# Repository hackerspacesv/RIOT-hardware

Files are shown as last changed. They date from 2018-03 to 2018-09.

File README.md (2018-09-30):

Hackerspace San Salvador RIOT OS Development Boards
===================================================
This repository contains all the design files for the boards supported by the
[RIOT OS](https://www.riot-os.org/) port mantained by the [Hackerspace
San Salvador](http://hackerspace.teubi.co/). You can find the RIOT OS port 
for the supported boards over
[https://github.com/hackerspacesv/RIOT](https://github.com/hackerspacesv/RIOT).

### Current boards supported
* **[ATSAMR21 Breakout Board](http://hackerspace.teubi.co/wiki/index.php?title=HSSV_ATSAMR21_Breakout_English)**: A development board to accelerate the deployment of
  IEEE 802.15.4 based networks on the 2.4Ghz band. It is based on the
  ATSAMR21G18-MR210UA module wich also includes support for antenna-diversity and
  a crypto-acceleration chip. This board was designed to be breadboard-friendly
  and includes USB support and power & LiPo battery management.
* **ATZB-RF-233-1-C breakout**: This is a breadboard-friendly breakout board for the
  module ATZB-RF-233-1-C, this module includes the easy-to-use AT8RF233 radio with
  a front-end-module with a Power-Amplifier & Low-Noise-Amplifier (PA/LNA) to greatly
  extend the range of the radio of IEEE 802.15.4 networks on the 2.4GHz band.

### Planned support
* **ATZB-RF-233-1-C breakout for the Omega Onion**: The Omega Onion is a low-cost
  system-on-a-module that runs a lightweight version of GNU/Linux. This breakout board
  should facilitate the creation of low-cost WiFi-802.15.4 bridges and edge routers.

### Board documentation

A guide to use this board with RIOT OS is available at the [Hackerspace San Salvador Wiki](http://hackerspace.teubi.co/wiki/index.php?title=HSSV_ATSAMR21_Breakout_English)

### Licensing and use
**Copyright 2018 Mario Gomez <mario.gomez@teubi.co>**

All files within this repository are licensed under the
Apache License, Version 2.0 (the "License") unless otherwise
specified in the individual files; you may not use this files
except in compliance with the License.

You may obtain a copy of the License at

    http://www.apache.org/licenses/LICENSE-2.0

Unless required by applicable law or agreed to in writing, software
and design files distributed under the License are distributed on an
"AS IS" BASIS, WITHOUT WARRANTIES OR CONDITIONS OF ANY KIND, either
express or implied.

See the License for the specific language governing permissions and
limitations under the License.

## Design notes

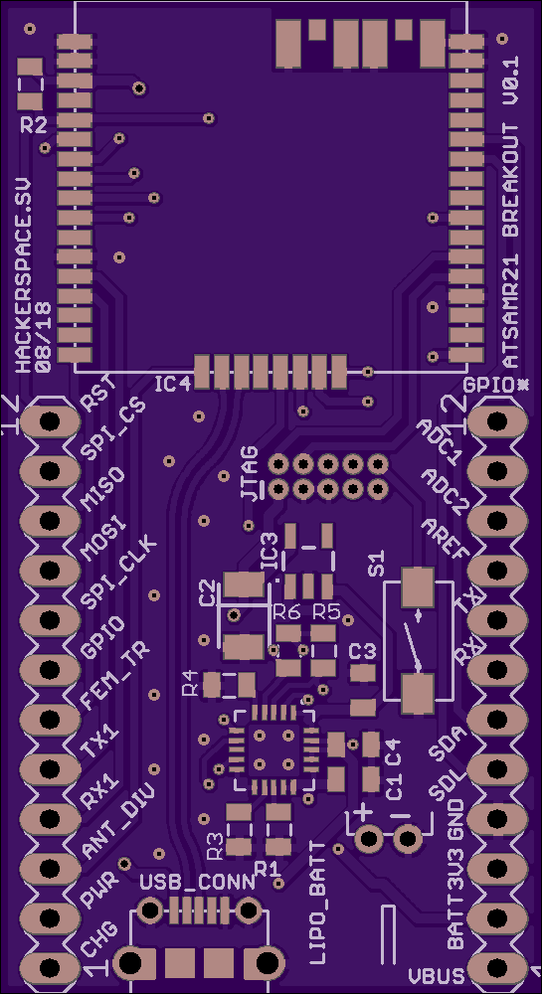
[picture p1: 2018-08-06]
boards/renders/ATSAMR21-Top.png

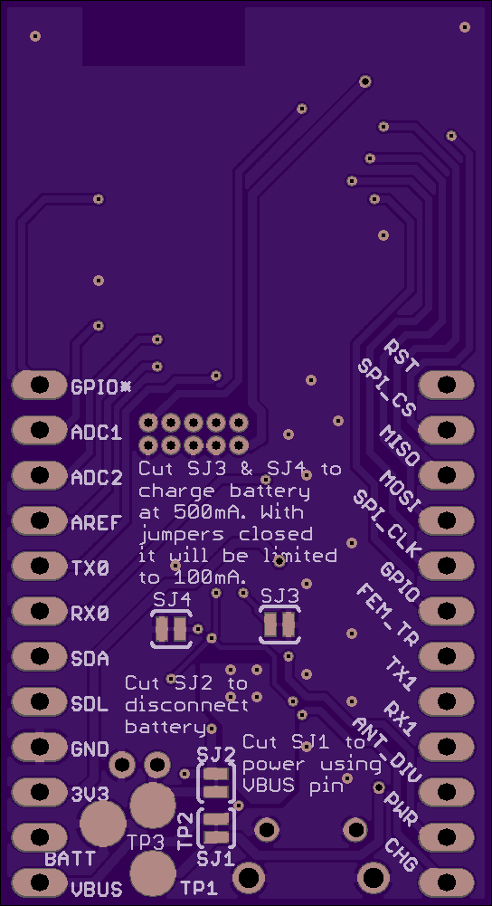
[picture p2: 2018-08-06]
boards/renders/ATSAMR21-Bottom.png

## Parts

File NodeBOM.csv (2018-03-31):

Qty | Value | Device | Package | Parts | Description | MF | MPN | OC_FARNELL | OC_NEWARK | PACKAGE | PROD_ID | SUPPLIER | TP_SIGNAL_NAME
1 |  | JST_2PIN-THM-RA | JST-PH-2-THM-RA | LIPO_BATT | JST 2-Pin Connectors of various flavors
2 |  | MA12-1 | MA12-1 | SV1, SV2 | PIN HEADER |  |  | unknown | unknown
1 | SI2301CDS-T1-GE3 | MOSFET-PCHANNEL | SOT23-3 | Q1 | Generic PMOSFET |  |  |  |  |  | TRANS-08285
2 | 10K | RESISTOR0805-RES | 0805 | R1, R2 | Resistor
1 | 1N5819HW-7-F | 1N5819HW-7-F | SOD123 | D1
1 | ATSAMR21G18-MR210UA | ATSAMR21G18-MR210UA | ATSAMR21G18A-MR210UA | IC4
1 | CORTEX_DEBUGPTH | CORTEX_DEBUGPTH | 2X5-PTH-1.27MM | JTAG | Cortex Debug Connector
1 | EVQ-PNF04M | EVQ-PNF04M | PANASONIC_EVQPE1/PN/5P | S1
1 | LTC4412 | LTC4412 | SOT23-6L | IC2
1 | MCP73831T-2ATI/OT | MCP73831T-2ATI/OT | SOT95P300X145-5N | IC1 | IC, BATT CHARGER, Li-Ion Li-Polymer, 500 mA |  | MCP73831T-2ATI/OT | 1834890 | 84R5196 | SOT23-5 |  | Microchip
1 | NCP4589DSN33T1G | NCP4589DSN33T1G | SOT23-5 | IC3
2 | SOLDERJUMPERTRACE | SOLDERJUMPERTRACE | SJ_2S-TRACE | SJ1, SJ2 | Solder Jumper
2 | TPB2,54 | TPB2,54 | B2,54 | TP1, TP2 | Test pad
2 | TPSB107M010R0400 | TPSB107M010R0400 | 1210-POLARIZED | C1, C2
1 | USB-MICRO-B | USB-MICRO-B | HPL511 | USB_CONN

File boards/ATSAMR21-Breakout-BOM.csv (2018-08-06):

Qty | Value | Device | Package | Parts | Description | MF | MPN | OC_FARNELL | OC_NEWARK | PROD_ID | TP_SIGNAL_NAME | VALUE
1 |  | JST_2PIN-THM-RA | JST-PH-2-THM-RA | LIPO_BATT | JST 2-Pin Connectors of various flavors
2 |  | MA12-1 | MA12-1 | SV1, SV2 | PIN HEADER |  |  | unknown | unknown
1 | 100K | RESISTOR0805-RES | 0805 | R3 | Resistor
4 | 10K | RESISTOR0805-RES | 0805 | R2, R4, R5, R6 | Resistor
1 | 10uF | 22UF-0805-6.3V-20% | 0805 | C4 | 22µF ceramic capacitors |  |  |  |  | CAP-08402 |  | 22uF
1 | 2K | RESISTOR0805-RES | 0805 | R1 | Resistor
2 | 4.7uF | 22UF-0805-6.3V-20% | 0805 | C1, C3 | 22µF ceramic capacitors |  |  |  |  | CAP-08402 |  | 22uF
1 | 47uF | TPSB107M010R0400 | 1210-POLARIZED | C2
1 | ATSAMR21G18-MR210UA | ATSAMR21G18-MR210UA | ATSAMR21G18A-MR210UA | IC4
1 | CORTEX_DEBUGPTH | CORTEX_DEBUGPTH | 2X5-PTH-1.27MM | JTAG | Cortex Debug Connector
1 | EVQ-PNF04M | EVQ-PNF04M | PANASONIC_EVQPE1/PN/5P | S1
1 | MCP73871T | MCP73871T | QFN-20 | U$1
1 | NCP4589DSN33T1G | NCP4589DSN33T1G | SOT23-5 | IC3
4 | SOLDERJUMPERTRACE | SOLDERJUMPERTRACE | SJ_2S-TRACE | SJ1, SJ2, SJ3, SJ4 | Solder Jumper
3 | TPB2,54 | TPB2,54 | B2,54 | TP1, TP2, TP3 | Test pad
1 | USB-MICRO-B | USB-MICRO-B | HPL511 | USB_CONN

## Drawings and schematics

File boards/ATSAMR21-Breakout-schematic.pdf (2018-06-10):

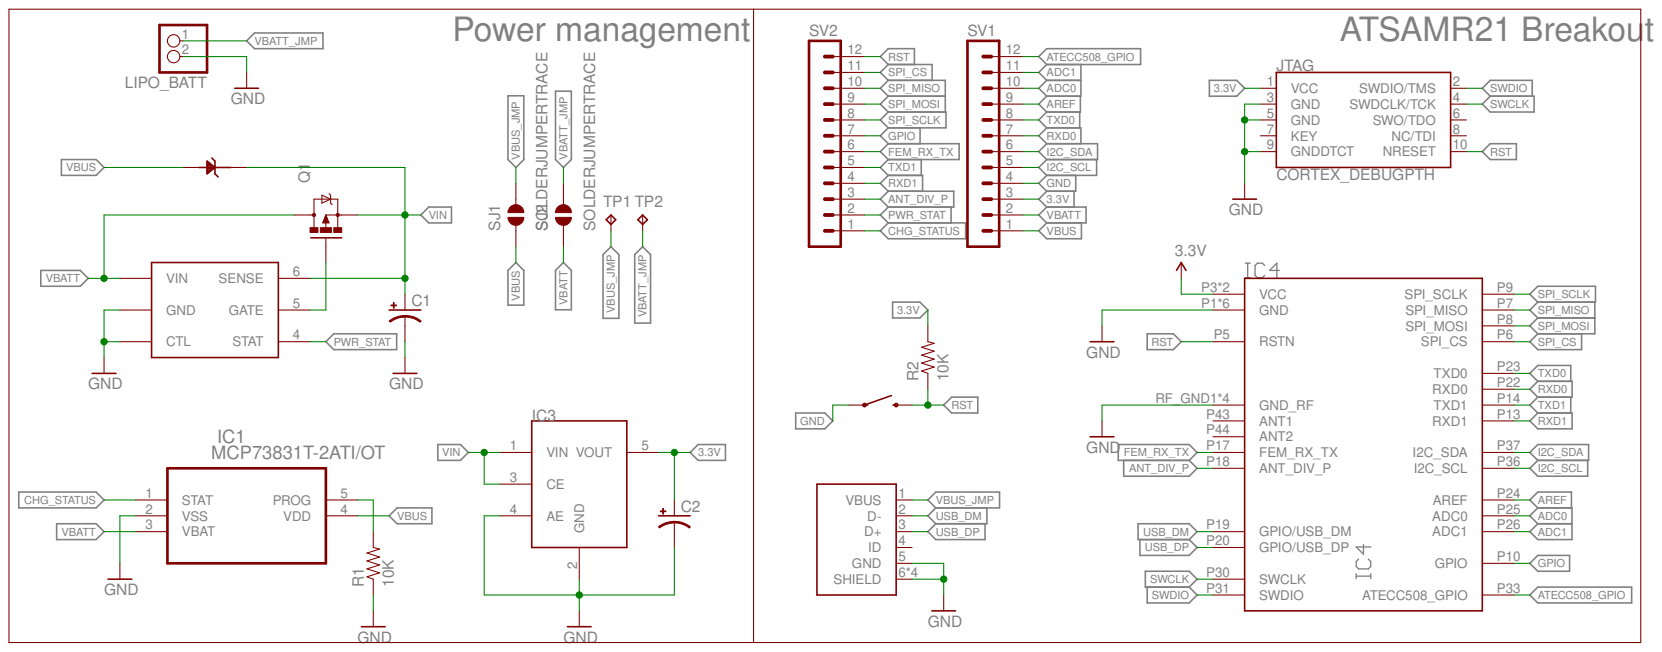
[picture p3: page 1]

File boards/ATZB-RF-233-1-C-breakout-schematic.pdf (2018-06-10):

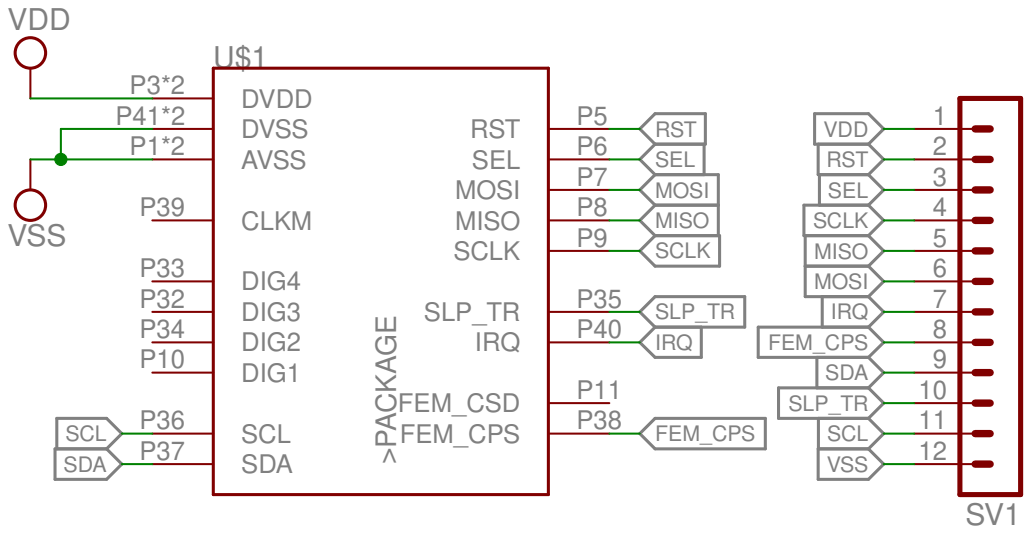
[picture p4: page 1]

>PACKAGE VSS VDD AVSS P1*2 DVDD P3*2 RST P5 SEL P6 MOSI P7 MISO P8 SCLK P9 DIG1 P10 FEM_CSD P11 DIG3 P32 DIG4 P33 DIG2 P34 SLP_TR P35 SCL P36 SDA P37 FEM_CPS P38 CLKM P39 DVSS P41*2 U$1 IRQ P40 SV1 123456789101112 VSS RST VDD SEL RST MOSI SEL MOSI MISO SCLK MISO SCLK SLP_TR SLP_TR IRQ IRQ FEM_CPS FEM_CPS SDA SDA SCL SCL

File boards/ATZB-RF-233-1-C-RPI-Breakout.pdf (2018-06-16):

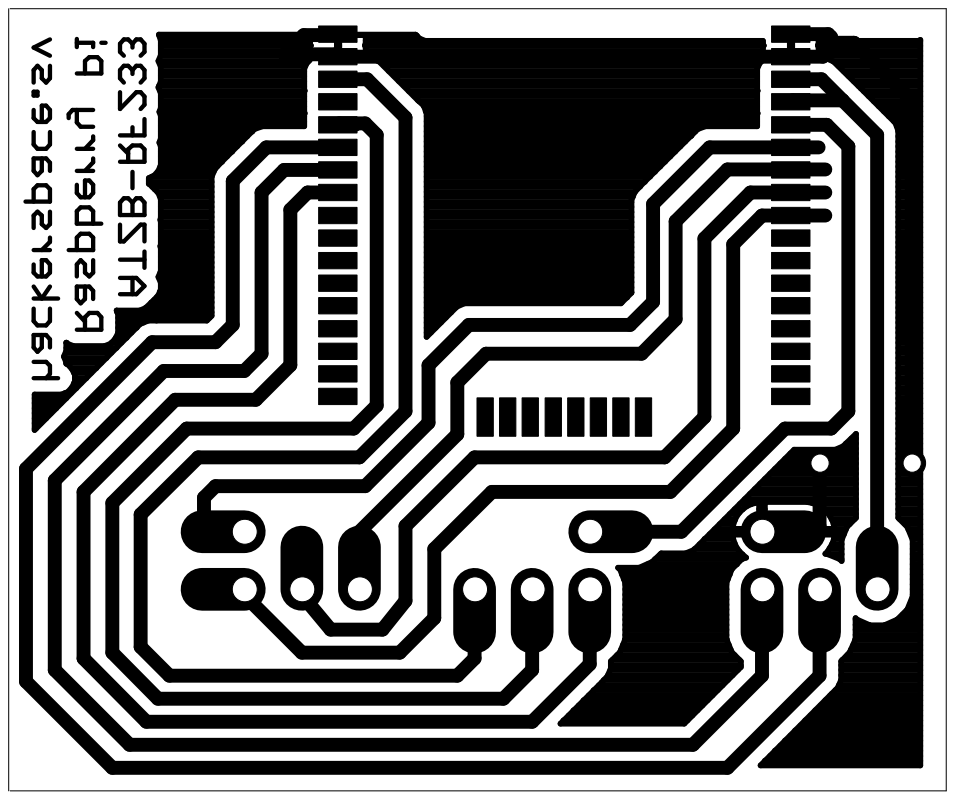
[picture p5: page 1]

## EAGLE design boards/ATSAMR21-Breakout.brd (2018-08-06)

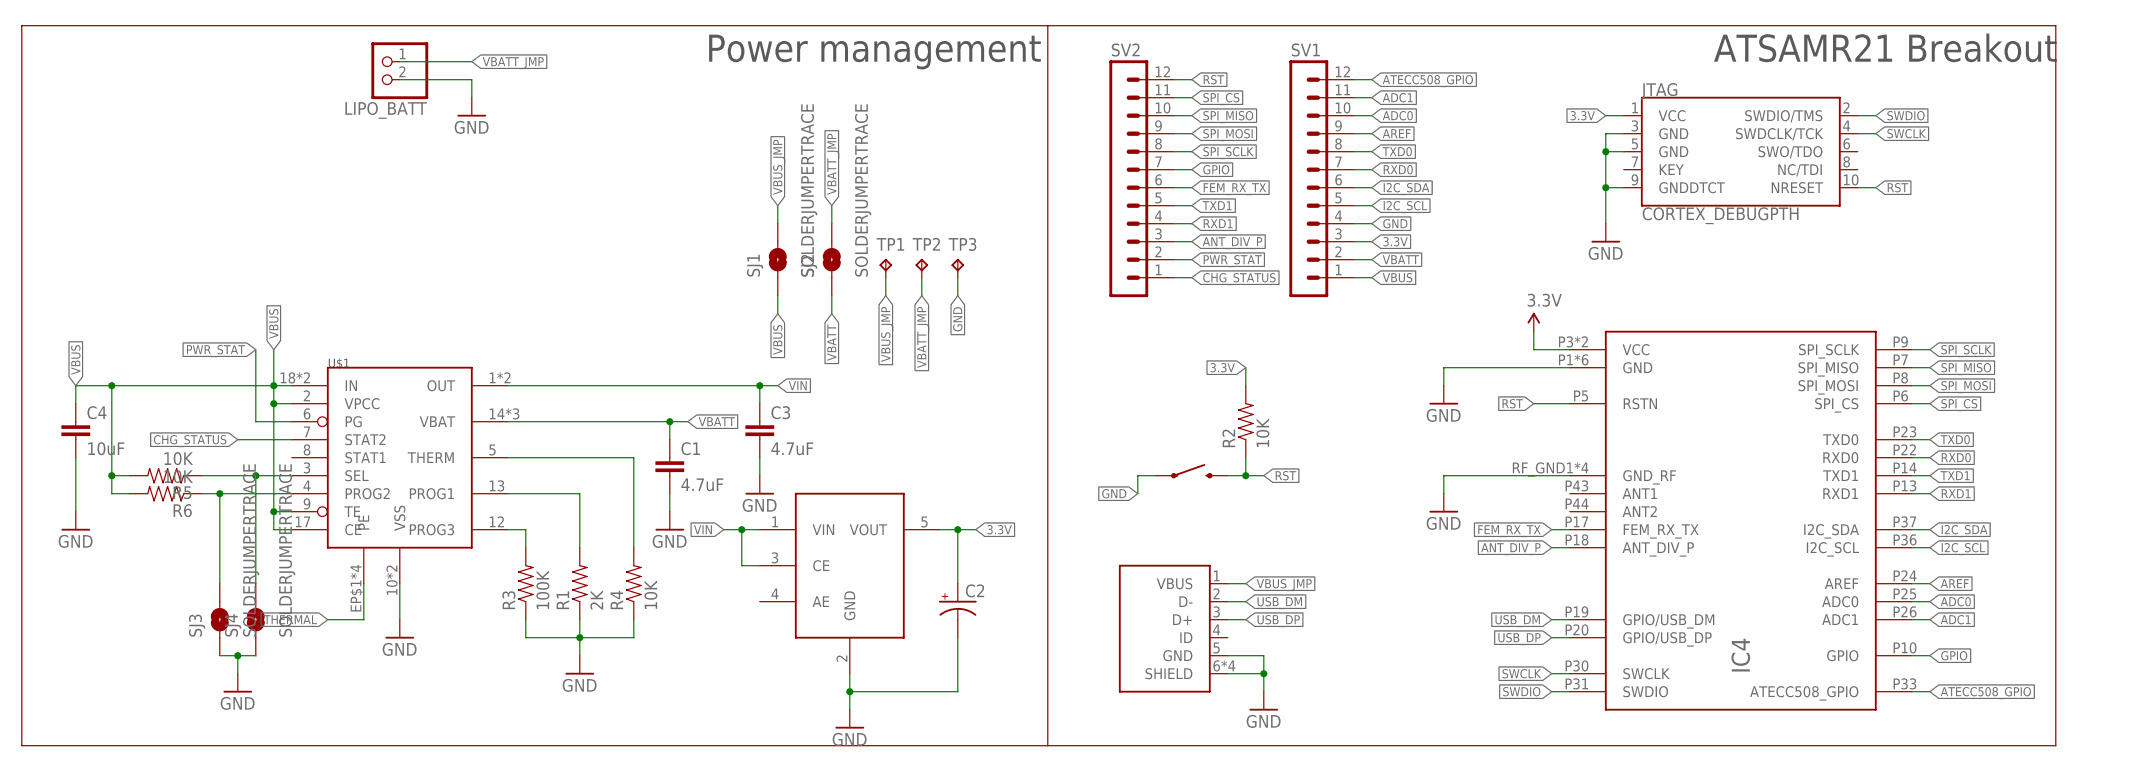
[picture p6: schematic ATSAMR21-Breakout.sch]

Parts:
C1, C3: 4.7uF; 0805
C2: 47uF; 1210-POLARIZED
C4: 10uF; 0805
IC3: NCP4589DSN33T1G; SOT23-5
IC4: ATSAMR21G18-MR210UA; ATSAMR21G18A-MR210UA
JTAG: CORTEX_DEBUGPTH; 2X5-PTH-1.27MM
LIPO_BATT: JST_2PIN-THM-RA; JST-PH-2-THM-RA
R1: 2K; 0805
R2, R4, R5, R6: 10K; 0805
R3: 100K; 0805
S1: EVQ-PNF04M; PANASONIC_EVQPE1/PN/5P
SJ1, SJ2, SJ3, SJ4: SOLDERJUMPERTRACE; SJ_2S-TRACE
SV1, SV2: MA12-1
TP1, TP2, TP3: TPB2,54; B2,54
U$1: MCP73871T; QFN-20
USB_CONN: USB-MICRO-B; HPL511

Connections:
3.3V: C2.1 (+), IC3.5 (VOUT), IC4.P3 (VCC), IC4.P4 (VCC), JTAG.1 (VCC), R2.2, SV1.3
ADC0: IC4.P25 (ADC0), SV1.10
ADC1: IC4.P26 (ADC1), SV1.11
ANT_DIV_P: IC4.P18 (ANT_DIV_P), SV2.3
AREF: IC4.P24 (AREF), SV1.9
ATECC508_GPIO: IC4.P33 (ATECC508_GPIO), SV1.12
CHG_STATUS: SV2.1, U$1.7 (STAT2)
FEM_RX_TX: IC4.P17 (FEM_RX_TX), SV2.6
GND: C1.2, C2.2 (-), C3.2, C4.2, IC3.2 (GND), IC4.P1 (GND), IC4.P2 (GND), IC4.P12 (GND), IC4.P29 (GND), IC4.P41 (GND), IC4.P42 (GND), IC4.RF_GND1 (GND_RF), IC4.RF_GND2 (GND_RF), IC4.RF_GND3 (GND_RF), IC4.RF_GND4 (GND_RF), JTAG.3 (GND), JTAG.5 (GND), JTAG.9 (GNDDTCT), LIPO_BATT.2 (1), R1.1, R3.1, R4.1, S1.P1 (1), SJ3.1, SJ4.1, SV1.4, TP3.TP, U$1.10 (VSS), U$1.11 (VSS), USB_CONN.5 (GND), USB_CONN.6 (SHIELD), USB_CONN.7 (SHIELD), USB_CONN.8 (SHIELD), USB_CONN.9 (SHIELD)
GPIO: IC4.P10 (GPIO), SV2.7
I2C_SCL: IC4.P36 (I2C_SCL), SV1.5
I2C_SDA: IC4.P37 (I2C_SDA), SV1.6
unnamed: R6.1, SJ3.2, U$1.4 (PROG2)
unnamed: R5.1, SJ4.2, U$1.3 (SEL)
unnamed: R3.2, U$1.12 (PROG3)
unnamed: R1.2, U$1.13 (PROG1)
unnamed: R4.2, U$1.5 (THERM)
PWR_STAT: SV2.2, U$1.6 (PG)
RST: IC4.P5 (RSTN), JTAG.10 (NRESET), R2.1, S1.P2 (2), SV2.12
RXD0: IC4.P22 (RXD0), SV1.7
RXD1: IC4.P13 (RXD1), SV2.4
SPI_CS: IC4.P6 (SPI_CS), SV2.11
SPI_MISO: IC4.P7 (SPI_MISO), SV2.10
SPI_MOSI: IC4.P8 (SPI_MOSI), SV2.9
SPI_SCLK: IC4.P9 (SPI_SCLK), SV2.8
SWCLK: IC4.P30 (SWCLK), JTAG.4 (SWDCLK/TCK)
SWDIO: IC4.P31 (SWDIO), JTAG.2 (SWDIO/TMS)
THERMAL: U$1.EP$1 (PE), U$1.EP$2 (PE), U$1.EP$3 (PE), U$1.EP$4 (PE)
TXD0: IC4.P23 (TXD0), SV1.8
TXD1: IC4.P14 (TXD1), SV2.5
USB_DM: IC4.P19 (GPIO/USB_DM), USB_CONN.2 (D-)
USB_DP: IC4.P20 (GPIO/USB_DP), USB_CONN.3 (D+)
VBATT: C1.1, SJ2.1, SV1.2, U$1.14 (VBAT), U$1.15 (VBAT), U$1.16 (VBAT)
VBATT_JMP: LIPO_BATT.1 (2), SJ2.2, TP2.TP
VBUS: C4.1, R5.2, R6.2, SJ1.1, SV1.1, U$1.2 (VPCC), U$1.9 (TE), U$1.17 (CE), U$1.18 (IN), U$1.19 (IN)
VBUS_JMP: SJ1.2, TP1.TP, USB_CONN.1 (VBUS)
VIN: C3.1, IC3.1 (VIN), IC3.3 (CE), U$1.1 (OUT), U$1.20 (OUT)

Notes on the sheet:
Power management
ATSAMR21 Breakout

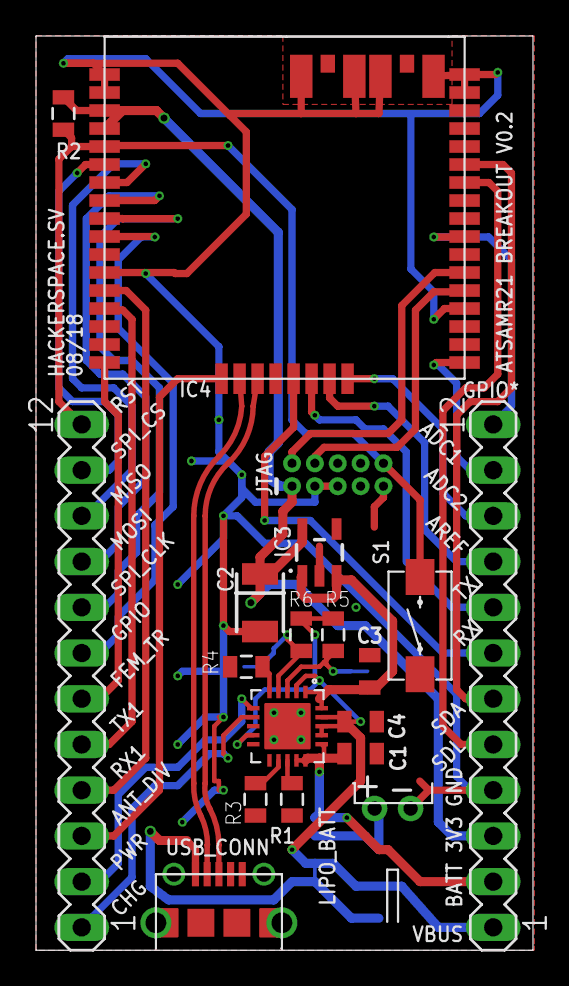
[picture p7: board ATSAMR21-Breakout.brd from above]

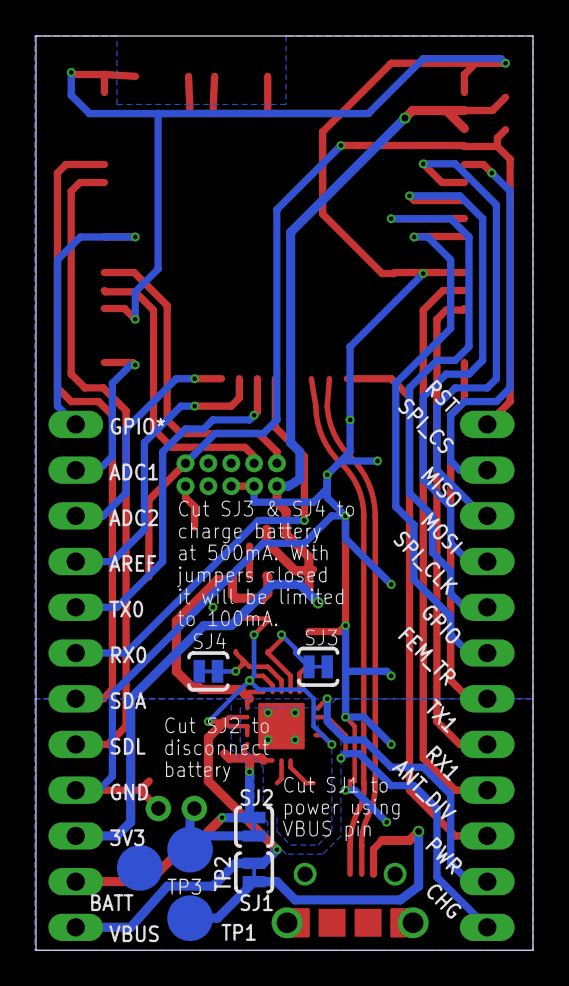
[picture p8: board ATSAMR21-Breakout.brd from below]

Board: 2 copper layers, 27.6 x 50.8 mm, 26 parts (7 on the bottom side), 37 nets.

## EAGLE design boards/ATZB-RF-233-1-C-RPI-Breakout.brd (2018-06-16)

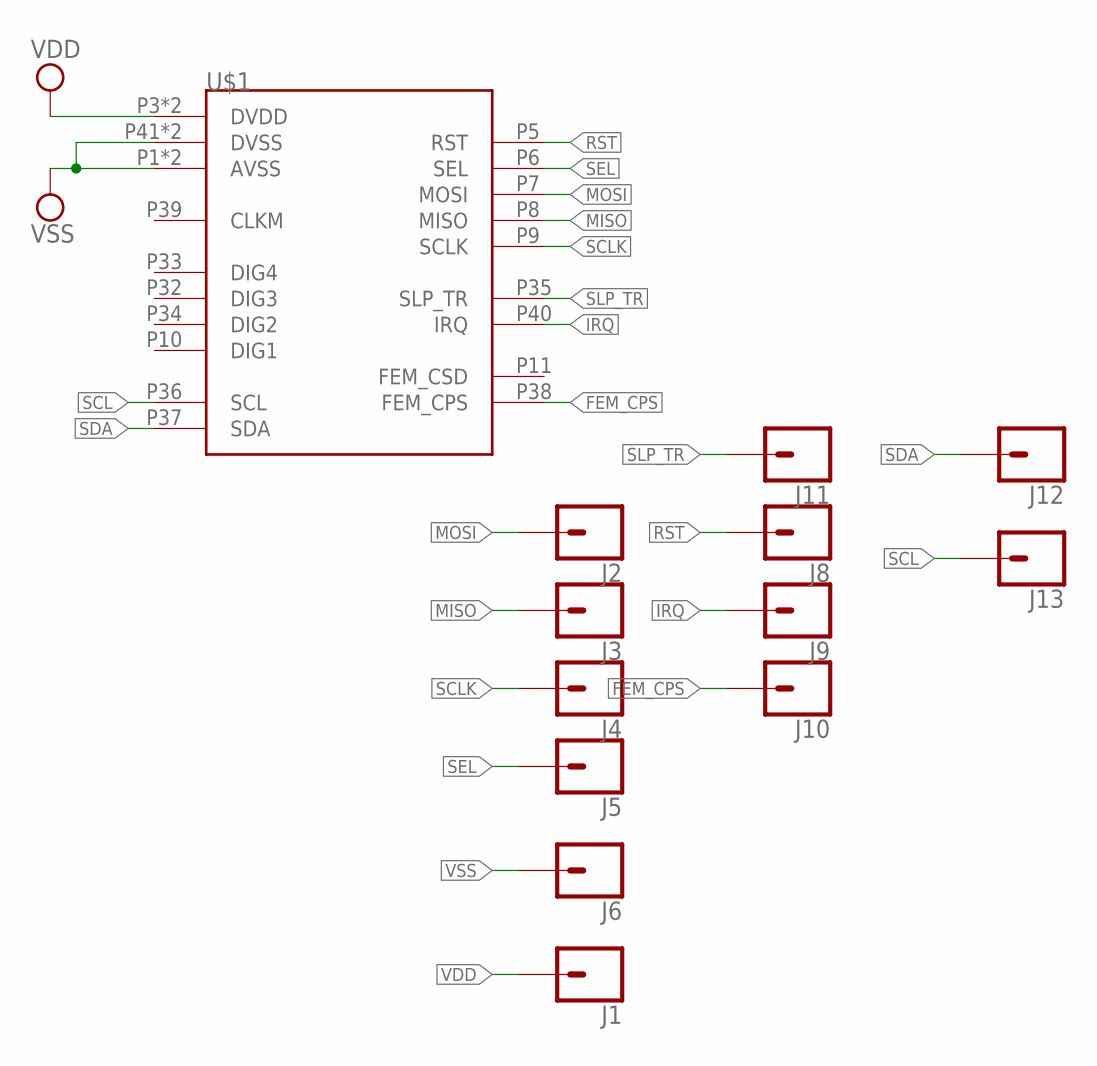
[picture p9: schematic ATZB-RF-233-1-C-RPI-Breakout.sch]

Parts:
J1, J2, J3, J4, J5, J6, J8, J9, J10, J11, J12, J13: CONN_01OFFSET; 1X01_OFFSET
U$1: ATZB-RF-233-1-C

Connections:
FEM_CPS: J10.1, U$1.P38 (FEM_CPS)
IRQ: J9.1, U$1.P40 (IRQ)
MISO: J3.1, U$1.P8 (MISO)
MOSI: J2.1, U$1.P7 (MOSI)
RST: J8.1, U$1.P5 (RST)
SCL: J13.1, U$1.P36 (SCL)
SCLK: J4.1, U$1.P9 (SCLK)
SDA: J12.1, U$1.P37 (SDA)
SEL: J5.1, U$1.P6 (SEL)
SLP_TR: J11.1, U$1.P35 (SLP_TR)
VDD: J1.1, U$1.P3 (DVDD), U$1.P4 (DVDD)
VSS: J6.1, U$1.P1 (AVSS), U$1.P2 (AVSS), U$1.P41 (DVSS), U$1.P42 (DVSS)

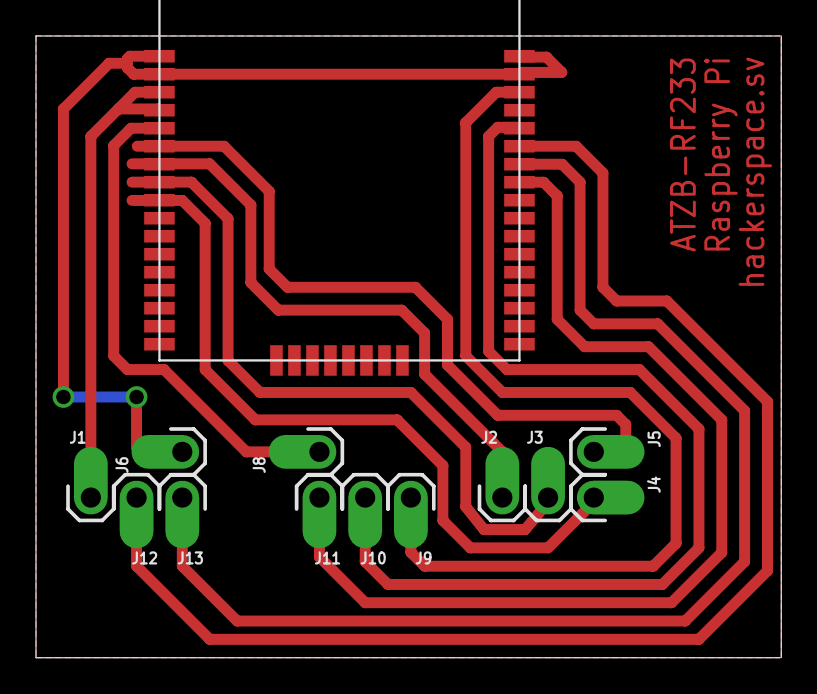
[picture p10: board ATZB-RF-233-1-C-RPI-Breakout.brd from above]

Board: 2 copper layers, 41.4 x 34.5 mm, 13 parts (0 on the bottom side), 12 nets.

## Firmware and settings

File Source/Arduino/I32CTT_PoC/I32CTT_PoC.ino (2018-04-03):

/*
 * 
 * This file is part of I32CTT (Integer 32-bit Control & Telemetry Transport).
 * Copyright (C) 2017 Mario Gomez.
 * 
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
 * You should have received a copy of the GNU General Public License
 * along with I32CTT.  If not, see <http://www.gnu.org/licenses/>.
 */

/*
 * Acerca de este archivo: Este sketch es la implementación de referencia
 * para el protocolo de enteros de 32 bits para control y transporte de
 * telemetría (I32CTT).
 */
// Utilizamos string.h para facilitar el formato de salida de Serie.
#include "I32CTT.h"
#include "I32CTT_NullEndpoint.h"
#include "I32CTT_ArduinoStreamInterface.h"
#include "I32CTT_Arduino802154Interface.h"
#include "MBL_ManualEndpoint.h"
#include <string.h>

I32CTT_Controller controller(8);

//I32CTT_NullInterface myInterface;
I32CTT_ArduinoStreamInterface serialInterface(Serial);
I32CTT_Arduino802154Interface ieee802154;
I32CTT_NullEndpoint idleEndpoint(I32CTT_Endpoint::str2id("NUL"));
MBL_ManualEndpoint manualEndpoint(I32CTT_Endpoint::str2id("MAN"));

void setup() {
  //while(!Serial);
  Serial.begin(9600);
  
  ieee802154.set_pan_id(0xCAFE);
  ieee802154.set_short_addr(0x0100);
  ieee802154.set_channel(C2480);
  ieee802154.set_dst_addr(0x0201);
  controller.set_interface(ieee802154);
  
  controller.add_mode_driver(idleEndpoint);
  controller.add_mode_driver(manualEndpoint);
  manualEndpoint.write(MBL_Registers::IS_ENABLED, HIGH);
  controller.enable_scheduler();
  controller.init();
  ieee802154.enable_pa(true);
  Serial.println("Running...");
}

unsigned long t_elapsed = 0;

void loop() {
  // put your main code here, to ru n repeatedly:
  controller.run();

  if((millis()-t_elapsed)>1000) {
    
    Serial.println("I'm alive");
    Serial.println("Trying to send..");
    
    controller.master.set_mode(1);
    controller.master.write_record({3, (uint32_t)0<<24});
    controller.master.try_send();
    
    //controller.master.set_mode(1);                                                                                                                                                                                                                                                                                                                                                                                                                                                                                                                                                                                                                                                                                                                                                                                                                                                                                                                                                                                                                                                                                                                                                                                                                                                                                                                                                                                                                                                                                                                                                                                                                                                                                                                                                                                                                                                                                                                                                                                                                                                                                                                                                                                                                                                                                                                                                                                                                                                                                                                                                                                                                                                                                                                                                                                                                                                                                                                                                                                                                                                                                                                                                                                                                                                                                                                                                                                                                                                                                                                                                                                                                                                                                                                                                                                                                                                                                                                                                                                                                                                                                                                                                                                                                                                                                                                                                                                                                                                                                                                                                                                                                                                                                                                                                                                                                                                                                                                                                                                                                                                                                                                                                                                                                                                                                                                                                                                                                                                                                                                                                                                                                                                                                                                                                                                                                                                                                                                                                                                                                                                                                                                                                                                                                                                                                                                                                                                                                                                                                                                                                                                                                                                                                                                                                                                                                                                                                                                                                                                                                                                                                                                                                                                                                                                                                                                                                                                                                                                                                                                                                                                                                                                                                                                                                                                                                                                                                                                                                                                                                                                                                                                                                                                                                                                                                                                                                                                                                                                                                                                                                                                                                                                                                                                                                                                                                                                                                                                                                                                                                                                                                                                                                                                                                                                                                                                                                                                                                                                                                                                                                                                                                                                                                                                                                                                                                                                                                                                                                                                                                                                                                                                                                                                                                                                                                                                                                                                                                                                                                                                                                                                                                                                                                                                                                                                                                                                                                                                                                                                                                                                                                                                                                                                                                                                                                                                                                                                                                                                                                                                                                                                                                                                                                                                                                                                                                                                                                                                                                                                                                                                                                                                                                                                                                                                                                                                                                                                                                                                                                                                                                                                                                                                                                                                                                                                                                                                                                                                                                                                                                                                                                                                                                                                                                                                                                                                                                                                                                                                                                                                                                                                                                                                                                                                                                                                                                                                                                                                                                                                                                                                                                                                                                                                                                                                                                                                                                                                                                                                                                                                                                                                                                                                                                                                                                                                                                                                                                                                                                                                                                                                                                                                                                                                                                                                                                                                                                                                                                                                                                                                                                                                                                                                                                                                                                                                                                                                                                                                                                                                                                                                                                                                                                                                                                                                                                                                                                                                                                                                                                                                                                                                                                                                                                                                                                                                                                                                                                                                                                                                                                                                                                                                                                                                                                                                                                                                                                                                                                                                                                                                                                                                                                                                                                                                                                                                                                                                                                                                                                                                                                                                                                                                                                                                                                                                                                                                                                                                                                                                                                                                                                                                                                                                                                                                                                                                                                                                                                                                                                                                                                                                       
   //controller.master.read_record(2);
    //controller.master.read_record(3); 
    //controller.master.try_send();
    
    t_elapsed = millis();
  }
  
  if(controller.master.available(CMD_AW)) {
    Serial.println("Answer received to WRITE");
  }
  if(controller.master.available(CMD_AR)) {
    Serial.println("Answer received to READ");
    for(int i=0;i<controller.master.records_available();i++) {
      I32CTT_RegData info = controller.master.read_RegData(i);
      Serial.print("Record: ");
      Serial.print(info.reg, HEX);
      Serial.print(" Data: ");
      Serial.println(info.data, HEX);
    }
  }

}

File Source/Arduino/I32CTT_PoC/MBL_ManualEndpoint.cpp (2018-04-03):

/*
 * 
 * This file is part of I32CTT (Integer 32-bit Control & Telemetry Transport).
 * Copyright (C) 2017 Mario Gomez.
 * 
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
 * You should have received a copy of the GNU General Public License
 * along with I32CTT.  If not, see <http://www.gnu.org/licenses/>.
 */
#include <stdint.h>
#include "I32CTT.h"
#include "MBL_ManualEndpoint.h"
#include "Arduino.h"
#define FP_OFFSET 24

MBL_ManualEndpoint::MBL_ManualEndpoint(uint32_t mode_id) : I32CTT_Endpoint(mode_id) {
  // Do nothing. Just call superclass parent
  this->is_enabled = 0;
  this->x = 0;
  this->y = 0;
  this->a = (uint32_t)1<<23; // 0.5
  this->b = (uint32_t)1<<23; // 0.5
  pinMode(19, OUTPUT);
  digitalWrite(19, LOW);
}
 
uint32_t MBL_ManualEndpoint::read(uint16_t addr) {
  uint32_t result;
  switch(addr) {
    case MBL_Registers::ID:
      result = this->id;
      break;
    case MBL_Registers::IS_ENABLED: // X
      result = this->is_enabled;
      break;
    case MBL_Registers::X: // X
      result = this->x;
      break;
    case MBL_Registers::Y: // Y
      result = this->y;
      break;
    case MBL_Registers::A: // a
      result = this->a;
      break;
    case MBL_Registers::B: // b
      result = this->b;
      break;
    default:
      result = 0x00;
  }
  return result; // Test Pattern
}

uint16_t MBL_ManualEndpoint::write(uint16_t addr, uint32_t data) {
  Serial.println("Manual Mode Write:");
  Serial.print(addr, HEX);
  Serial.print(" ");
  Serial.println(data, HEX);
  digitalWrite(19, !digitalRead(19));
  
  switch(addr) {
    case MBL_Registers::IS_ENABLED: // Is enabled
      if(data!=this->is_enabled)
        this->is_enabled = data>0;
      break;
    case MBL_Registers::X: // X
      if(data!=this->x)
        this->x = data;
      break;
    case MBL_Registers::Y: // Y
      if(data!=this->y)
        this->y = data;
      break;
    case MBL_Registers::A: // a
      if(data!=this->a)
        this->a = data;
      break;
    case MBL_Registers::B: // b
      if(data!=this->b)
        this->b = data;
      break;
    default:
      break;
  }
  return addr; // Null driver always return a valid address
}
  uint16_t result;

void MBL_ManualEndpoint::init() {
  // Set pin modes.
  pinMode(MBL_M1A, OUTPUT);
  digitalWrite(MBL_M1A, LOW);
  pinMode(MBL_M1B, OUTPUT);
  digitalWrite(MBL_M1B, LOW);
  pinMode(MBL_M2A, OUTPUT);
  digitalWrite(MBL_M2A, LOW);
  pinMode(MBL_M2B, OUTPUT);
  digitalWrite(MBL_M2B, LOW);
}

static inline uint32_t fp_ABS(uint32_t a) {
  uint32_t result = 0;
  if(a&0x80000000) {
    result = !a + (1<<FP_OFFSET);
  } else {
    result = a;
  }
  return result;
}

static inline uint32_t fp_MUL(uint32_t a, uint32_t b) {
  return (((uint64_t)a * (uint64_t)b) >> FP_OFFSET) | ((a&0x80000000) ^ (b&0x80000000)); 
}

static inline float to_FLOAT(uint32_t val) {
  return ((int32_t)val)/((float)(1<<FP_OFFSET));
}


void MBL_ManualEndpoint::update() {
  uint8_t pwm_val_m1a, pwm_val_m1b, pwm_val_m2a, pwm_val_m2b;

  uint32_t power1 = fp_MUL(this->a,this->y)+fp_MUL(this->b,this->x);
  uint32_t power2 = fp_MUL(this->a,this->y)-fp_MUL(this->b,this->x);

  pwm_val_m1a = (power1&0x80000000) ? fp_MUL(0x7F<<FP_OFFSET,fp_ABS(power1))>>FP_OFFSET : 0;
  pwm_val_m1b = (power1&0x80000000) ? 0 : fp_MUL(0x7F<<FP_OFFSET,fp_ABS(power1))>>FP_OFFSET;
  pwm_val_m2a = (power2&0x80000000) ? fp_MUL(0x7F<<FP_OFFSET,fp_ABS(power2))>>FP_OFFSET : 0;
  pwm_val_m2b = (power2&0x80000000) ? 0 : fp_MUL(0x7F<<FP_OFFSET,fp_ABS(power2))>>FP_OFFSET;
  
  analogWrite(MBL_M1A, pwm_val_m1a);
  analogWrite(MBL_M1B, pwm_val_m1b);
  analogWrite(MBL_M2A, pwm_val_m2a);
  analogWrite(MBL_M2B, pwm_val_m2b);

}

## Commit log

2018-03-30 Added land pattern for ATSAMR21G18-MR210UA and ATZB-RF-233-1-CR
    [Node.brd, Node.sch, OnionPiShield.brd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]
2018-03-31 Finished breakout board for ATSAMR21 This version is available at OSHPark Changes: +Breakout board finished +BOM updated with available components +Fixed directory structure
    [ATSAMR21-Breakout.brd, ATSAMR21-Breakout.sch, Node.brd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]
2018-04-01 Added breakout board for ATZB-RF-233-1-C.
    [ATSAMR21-Breakout.brd, ATSAMR21-Breakout.sch, ATZB-RF-233-1-C-breakout.brd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]
2018-04-03 Added Arduino examples for Teensy and ATZB-RF-233-1-C
2018-06-10 Added PDF versions of schematic files.
2018-06-16 Added new breakout board for ATZB-RF233 for Raspberry Pi.
    [ATZB-RF-233-1-C-RPI-Breakout.brd, ATZB-RF-233-1-C-RPI-Breakout.sch, ATZB-RF-233-1-C-breakout.brd]
2018-08-06 Changed Power-Path design.
    [ATSAMR21-Breakout-BOM.csv, ATSAMR21-Breakout.brd, ATSAMR21-Breakout.sch]
2018-08-06 Fixed charge management symbol
    [ATSAMR21-Breakout.brd, ATSAMR21-Breakout.sch]
2018-09-23 Added an script for programming the bootloader onto the atsamr21-breakout board.
2018-09-23 Minor fixes to the bootloader flasher makefile for the atsamr21-breakout board.

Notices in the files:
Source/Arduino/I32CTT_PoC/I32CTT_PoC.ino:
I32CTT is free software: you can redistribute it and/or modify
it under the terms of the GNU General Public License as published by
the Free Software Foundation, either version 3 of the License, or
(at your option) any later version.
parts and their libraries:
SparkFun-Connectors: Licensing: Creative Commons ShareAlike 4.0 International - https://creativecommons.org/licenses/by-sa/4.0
